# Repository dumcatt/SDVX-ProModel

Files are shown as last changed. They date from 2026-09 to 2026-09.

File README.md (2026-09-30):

# SDVX-ProModel
Convert your Sound Voltex panel into a controller



# Features
- Almost 1:1 to a real cabinet
- Side LED support
- Headphone Jack
- Adapter plate for [Yuancon](https://shop.yuancon.io/products/yuancon-sdvm-encoder-adjustable-high-precision-control-module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) style encoder/knobs

# Requirements
- SDVX Control panel from a Nemsys Cabinet
- Access to a Laser cutter that is at least 80x40cm big (or any laser cutting service)
- Access to a 3D Printer (or any 3D printing service)
- Some mounting hardware
- Electronics
- DIY Skills (Mostly Woodworking)

# Helpful resources
-  [Rhythm Cons Wiki](https://rhythm-cons.wiki/w/Main_Page)
-  [Cons&Stuff Discord](https://discord.com/invite/fknwz8s)
-  [The original conversion](https://github.com/speedypotato/SDVX-Panel-Conversion)

# Notes
- This project won't go over any of the wiring for the deck
- Some tolerances may be too tight
- no mounting holes for the cabinet magnets
- no mounting for I/O Board

# Bill of Materials
| Part | Amount | Notes |
| :--: | :--: | :--: |
| SDVX Panel | 1 | Assumes that yours has all buttons/switches|
| IO Board | 1 | Im using [FluffyFlash](https://github.com/Curfewshino/FlufflyFlash) in my build|
| Addressable LED Strip | 1 | 144/m |
| M4x16 Screws | 14 | Hex or philips is fine |
| M4 Tee Nuts | 8 | |
| M4 Flange Nuts | 6 | |
| M3x16 Screws | 4 | |
| M3 Nuts | 4 | |
| M4x5 Self tap screws | 20 | | 
| Rubber Feet | 8 | |
| 30mm snap-in buttons | 2 | |
| Cabinet Magnets | 4 | |
| 3.5mm jack | 1 | |
| Black Spray Paint | 1 | |
| wood | | 8 and 4mm |
| acrylic | | 1 and 3mm|
| some filament | | PLA is fine|

# Lasercut Wood Parts
| Filename | Amount | Thickness | Notes |
| :--: | :--: | :--: | :--: |
| [Top.dxf](DXFs/Top.dxf)  | 1 | 8mm | |
| [Side.dxf](DXFs/Side.dxf)| 2 | 8mm | |
| [Back.dxf](DXFs/Back.dxf)| 1 | 8mm | |
| [FrontLeft.dxf](DXFs/FrontLeft.dxf)| 1 | 8mm | |
| [FrontRight.dxf](DXFs/FrontRight.dxf)| 1 | 8mm | Cut 2 if you don't want the headphone jack|
| [Front.dxf](DXFs/Front.dxf) | 1 | 8mm | |
| [Center.dxf](DXfs/Center.dxf)| 2 | 8mm | |
| [BottomCover.dxf](DXFs/BottomCover.dxf)| 1 | 4mm |

# Lasercut Acrylic parts
| Filename | Amount | Thickness | Notes |
| :--: | :--: | :--: | :--: |
| [FrontPlate.dxf](DXFs/FrontPlate.dxf)| 1 | 1mm | Requires engraving |
| [HeadphonePlate.dxf](DXFs/HeadphonePlate.dxf)| 1 | 1mm | Requires Engraving|
| [KFC deck sidepiece.dxf](DXFs/KFC%20deck%20sidepiece.dxf)| 2 | 3mm | Requires the use of a line bender |

# 3D Printed Parts

| Filename | Amount | Notes |
| :--: | :--: | :--: |
| [LeftWedge.stl](STLs/LeftWedge.stl) | 1 | Has the headphone jack slot |
| [RightWedge.stl](STLs/RightWedge.stl) | 1 | Print 2 if you don't want the headphone jack  |
| [USBPlate.stl](STLs/USBPlate.stl) | 1 | |

# Assembly
- Glue pieces together with wood glue
- Spray paint the case
- Secure the cabinet magnets and wedges with self tappers

# Pics



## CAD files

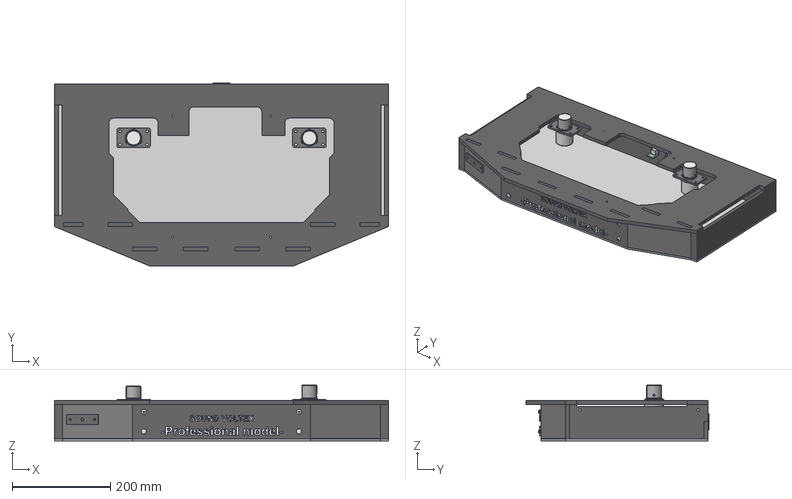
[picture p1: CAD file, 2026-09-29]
CAD/SdvxPanel (Assembly).step
680.0 x 372.0 x 113.6 mm
THS JIS B 1111 - M4.5x20 Steel 4.6 Chrome x 5
KnobAdapter x 2
Chinese 600 PPR Encoder x 2
Knob^SVRE9 knob assembly mod x 2
usbmodule

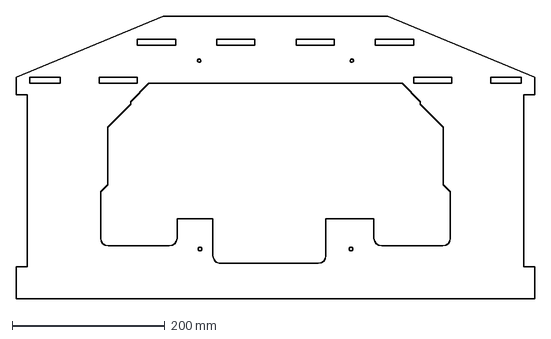
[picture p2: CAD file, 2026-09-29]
DXFs/Top.dxf
680.0 x 370.0 mm

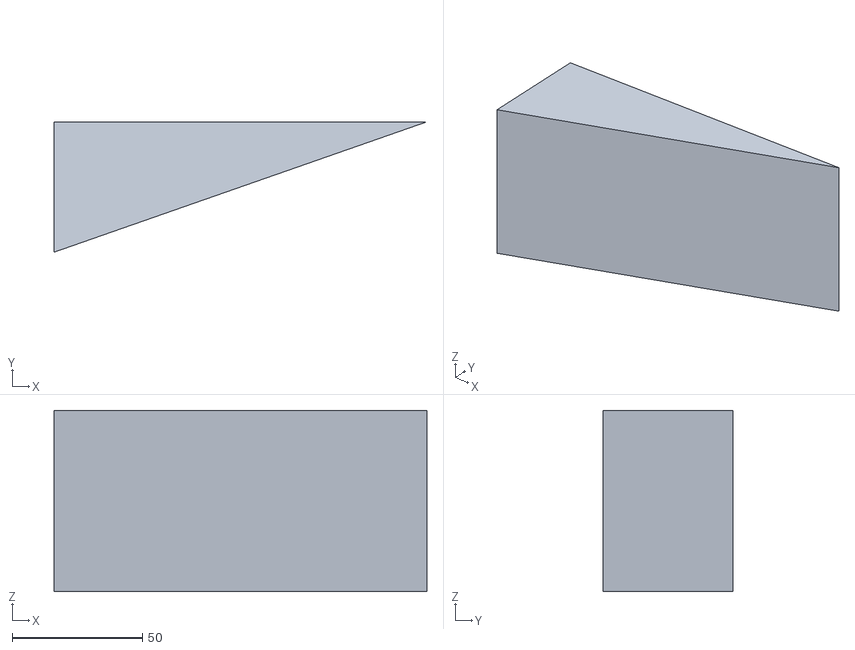
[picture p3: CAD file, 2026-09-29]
STLs/RightWedge.stl
143.0 x 50.0 x 69.5

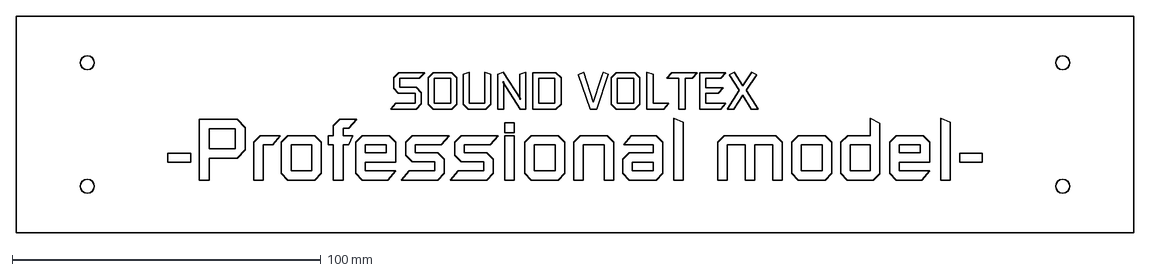
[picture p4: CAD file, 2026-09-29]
DXFs/FrontPlate.dxf
362.0 x 70.0 mm

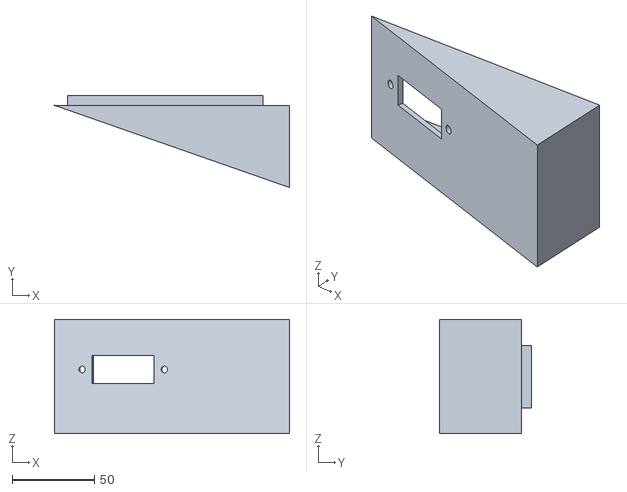
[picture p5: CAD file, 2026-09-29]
STLs/LeftWedge.stl
143.0 x 56.0 x 69.5

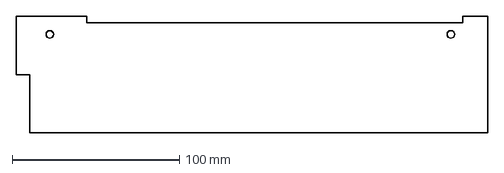
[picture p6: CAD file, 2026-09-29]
DXFs/Side.dxf
282.0 x 70.0 mm

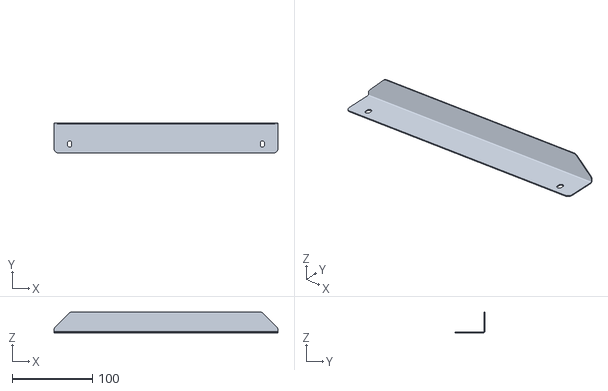
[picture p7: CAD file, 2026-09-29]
STLs/KFC deck sidepiece.stl
279.0 x 37.0 x 26.0

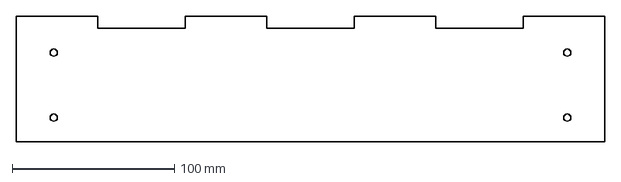
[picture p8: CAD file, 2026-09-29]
DXFs/Front.dxf
362.0 x 77.5 mm

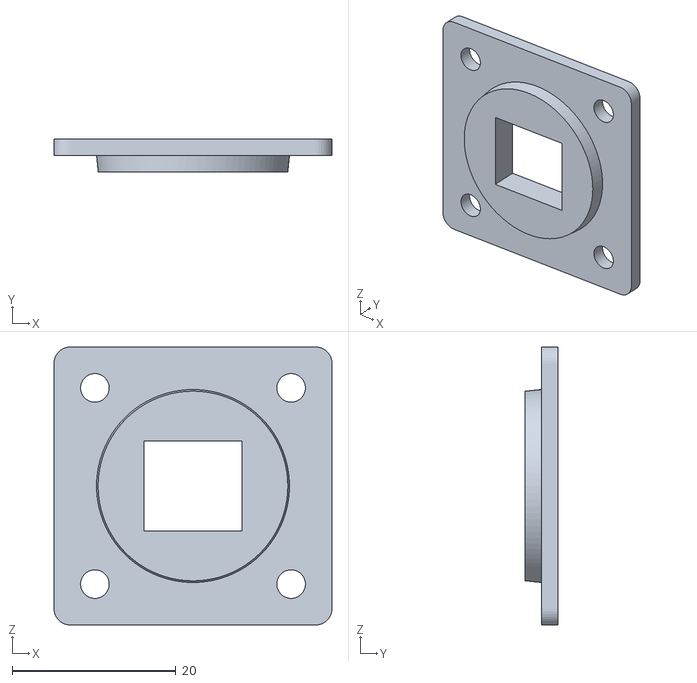
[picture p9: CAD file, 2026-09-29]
STLs/USBPlate.stl
34.0 x 4.00 x 34.0

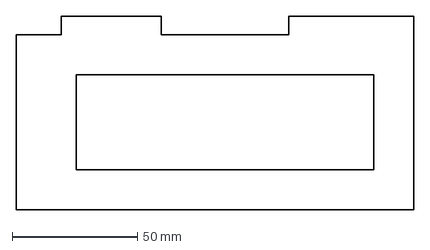
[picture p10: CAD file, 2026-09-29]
DXFs/FrontLeft.dxf
159.0 x 77.5 mm

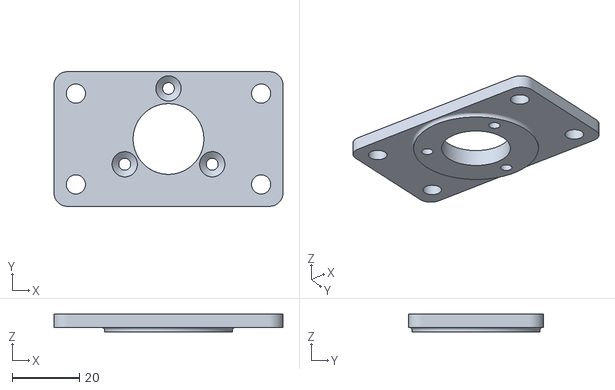
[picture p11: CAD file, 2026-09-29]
STLs/KnobAdapterPlate.stl
68.0 x 40.0 x 5.25

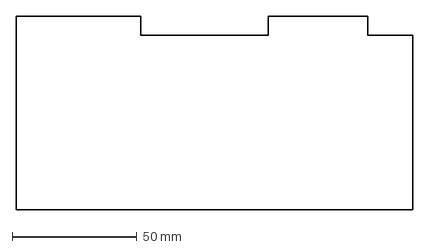
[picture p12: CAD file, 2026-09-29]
DXFs/FrontRight.dxf
159.0 x 77.5 mm

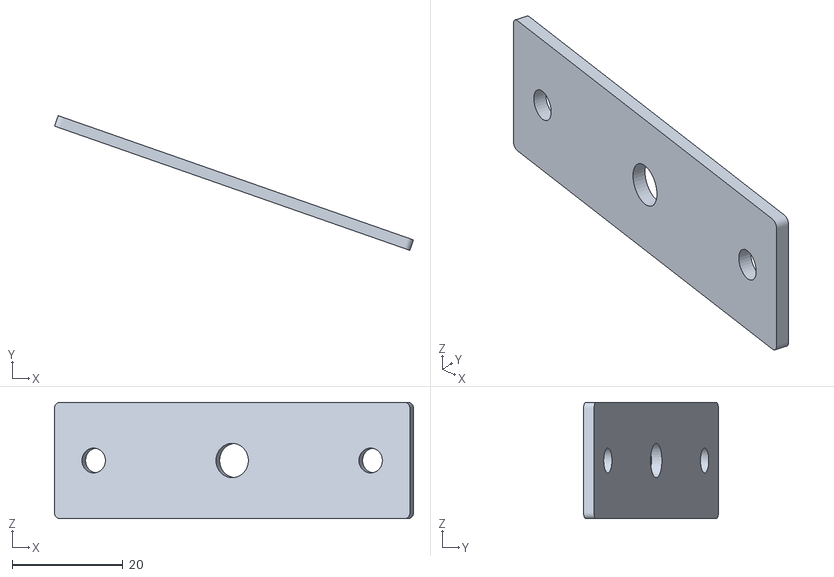
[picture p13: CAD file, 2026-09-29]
STLs/HeadphonePlate.stl
64.8 x 24.3 x 21.0

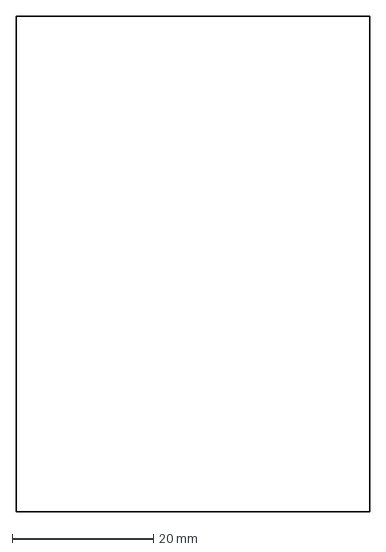
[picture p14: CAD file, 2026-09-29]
DXFs/Center.dxf
50.0 x 70.0 mm

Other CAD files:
DXFs/BottomCover.dxf
DXFs/Back.dxf
CAD/SdvxPanel (Assembly).f3z
DXFs/HeadphonePlate.dxf
DXFs/KFC deck sidepiece.dxf

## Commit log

2026-09-29 Initial commit
    Initial
    [Back.dxf, BottomCover.dxf, Center.dxf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]
2026-09-29 Add CAD
    [SdvxPanel (Assembly).f3z, SdvxPanel (Assembly).step]
